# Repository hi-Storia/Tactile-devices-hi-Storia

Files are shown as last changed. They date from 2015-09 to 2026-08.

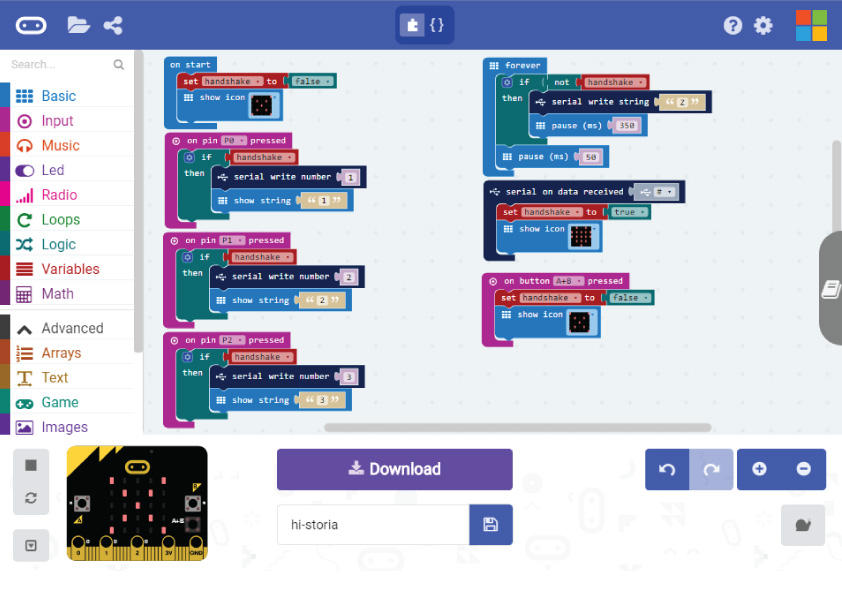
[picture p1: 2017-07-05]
Firmware/Microbit/microbit-blocks-for-hi-storia-player.jpg

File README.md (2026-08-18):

# Hi-Storia Tactile Devices

<p align="center">
  <a href="https://www.hi-storia.it/audioguida-tattile/">
    Hi-Storia tactile device
  </a>
</p>

Open-source firmware and hardware references for **Hi-Storia tactile audio guides**: 3D-printed cultural heritage models with capacitive touch activators that trigger audio and multimedia content.

Learn more about the project:

- [What is a Hi-Storia tactile audio guide?](https://www.hi-storia.it/audioguida-tattile/)
- [Hardware and electronics](https://www.hi-storia.it/audioguida-tattile/hardware/)

## Current reference architecture

The **2026 reference implementation** for new Hi-Storia tactile devices is:

**Arduino UNO R4 Minima + R4_Touch + USB serial + Hi-Storia Go on Android**

```text
3D-printed tactile model
        ↓
capacitive activators
        ↓
Arduino UNO R4 Minima
        ↓
USB serial · T1 / T2 / T3 / ...
        ↓
Android smartphone
        ↓
Hi-Storia Go
        ↓
audio and interactive content
```

This architecture keeps the electronics simple, visible and repairable, while allowing an Android smartphone — including a reused or refurbished device — to act as the player and configuration interface.

## Supported hardware

| Board | Touch sensing | Connection | Status | Field-tested on |
| --- | --- | --- | --- | --- |
| **Arduino UNO R4 Minima** | `R4_Touch` / built-in CTSU | USB serial | **Reference hardware** | Torpignattara, Rome (2026) |
| **ESP32** | Native capacitive touch | USB serial + Bluetooth Classic | **Supported alternative** | San Flaviano (2026) |
| Arduino UNO R3 | Legacy capacitive sensing | USB serial | Legacy | Previous Hi-Storia devices |
| Arduino Micro | Legacy capacitive sensing | USB serial | Legacy | Previous Hi-Storia devices |
| BBC micro:bit | Previous implementation | Serial / project-specific | Legacy / educational | Previous Hi-Storia workshops |

The older implementations remain in the repository for compatibility, documentation and educational reuse.

## Arduino UNO R4 Minima

The UNO R4 Minima is the current reference board for new Hi-Storia devices.

The reference firmware uses the [`R4_Touch`](https://github.com/delta-G/R4_Touch) library to access the capacitive touch sensing unit built into the UNO R4 microcontroller.

Current reference sketch:

```text
Firmware/Arduino/historia_arduino_uno_r4/
└── historia_arduino_uno_r4.ino
```

The current Hi-Storia configuration uses touch-capable pins:

```text
2, 3, 8, 9, 11
```

### R4_Touch hardware note

On the **UNO R4 Minima**, `R4_Touch` requires a capacitor between **TSCAP (pin 10)** and **GND**. The library recommends approximately **10 nF**.

The firmware uses single-scan touch acquisition, the configuration field-tested on the Torpignattara tactile device.

## ESP32

ESP32 is maintained as a supported alternative for installations where its integrated features are useful.

The Hi-Storia ESP32 firmware uses:

- native ESP32 capacitive touch inputs;
- USB serial;
- Bluetooth Classic;
- persistent threshold configuration through `Preferences`.

Reference sketch:

```text
Firmware/ESP32/historia_esp32/
└── historia_esp32.ino
```

This implementation was field-tested on the **San Flaviano Hi-Storia tactile device (2026)**.

The reference Hi-Storia Go workflow currently uses USB serial. Bluetooth support in the ESP32 firmware can also be used by compatible players or custom integrations.

## Serial protocol

Current firmware implementations share a small text-based protocol.

### Board → player

```text
T1
T2
T3
...
MSG:HI-STORIA READY
```

`T<n>` means that tactile activator number `n` has been touched.

### Player → board

```text
Z
SET:6500
PING
```

| Command | Meaning |
| --- | --- |
| `Z` | Reset the currently active tactile track |
| `SET:<value>` | Change and persist the touch threshold |
| `PING` | Test the connection; the board replies with `PONG` |

This keeps the firmware independent from the content itself: the board reports tactile events, while the player decides which audio or multimedia content is associated with each activator.

## Default player: Hi-Storia Go

The reference player for current Hi-Storia tactile devices is **[Hi-Storia Go](https://github.com/hi-Storia/Hi-Storia-Go)**, an open-source Android application.

Hi-Storia Go turns an Android smartphone into the player for a tactile model. It receives events such as `T1`, `T2` and `T3` from the board and associates them with the corresponding audio tracks.

The app is designed to make projects configurable directly from the phone and to support the reuse of older Android smartphones as dedicated players.

Hi-Storia Go is currently under active development and its public repository should be considered an **alpha release**.

## Repository layout

```text
Firmware/
├── Arduino/
│   ├── historia_arduino_uno_r4/
│   │   └── historia_arduino_uno_r4.ino
│   ├── historia_arduino_uno_r3/
│   │   └── historia_arduino_uno_r3.ino
│   └── historia_arduino_micro/
│       └── historia_arduino_micro.ino
│
├── ESP32/
│   └── historia_esp32/
│       └── historia_esp32.ino
│
└── Microbit/
    └── ...
```

Some legacy material may still use older directory or sketch names. These files document previous generations of Hi-Storia hardware.

## About Hi-Storia

Hi-Storia is an educational and cultural heritage project in which students and teachers research local heritage and build interactive tactile devices through 3D modelling and printing, electronics, coding, writing and audio production.

The tactile models are designed for shared use and include interaction modes intended to improve access for blind and partially sighted visitors.

More information:

- [Hi-Storia](https://www.hi-storia.it/)
- [Tactile audio guides](https://www.hi-storia.it/audioguida-tattile/)
- [Hardware](https://www.hi-storia.it/audioguida-tattile/hardware/)
- [Hi-Storia Go](https://github.com/hi-Storia/Hi-Storia-Go)

## License

The firmware in this repository is released under the **GNU General Public License v2.0 (GPL-2.0)**. See [LICENSE](LICENSE).

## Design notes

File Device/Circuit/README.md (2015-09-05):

# Importante
Nell'esempio, i file 3D per il dispositivo rappresentante la Basilica di San Bernardino a L'Aquila
In attesa del file Eagle, importiamo il file Dwg

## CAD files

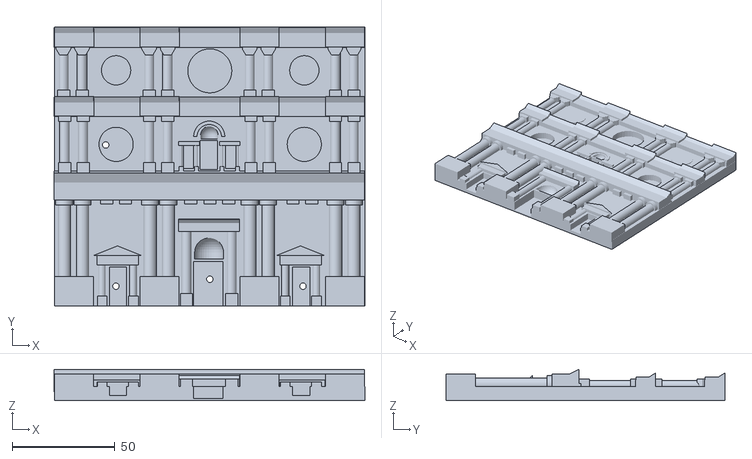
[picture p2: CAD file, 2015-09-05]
Device/3D print/Edificio.stl
151.3 x 135.7 x 15.2

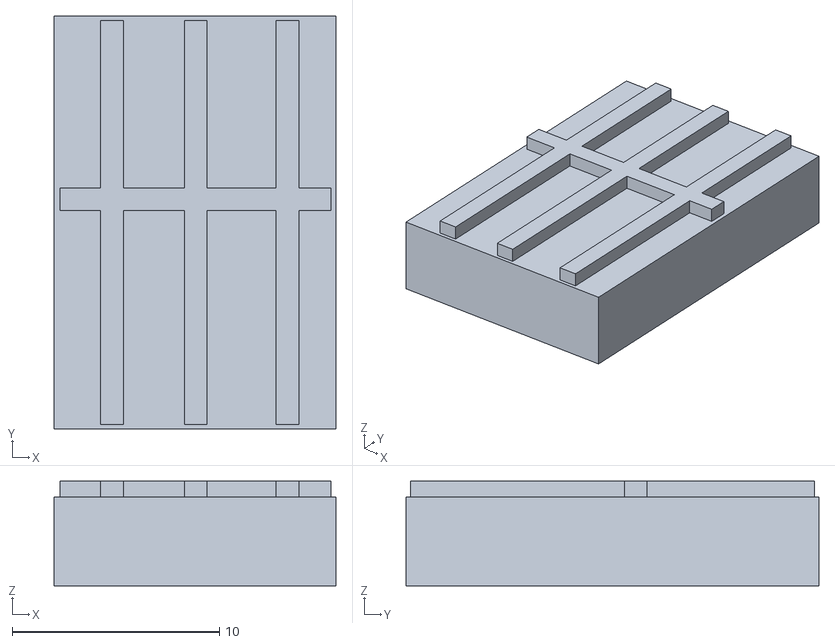
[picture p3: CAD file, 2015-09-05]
Device/3D print/Elementi conduttivi/5.2 portone principale conduttivo (repaired).stl
13.6 x 19.9 x 5.05

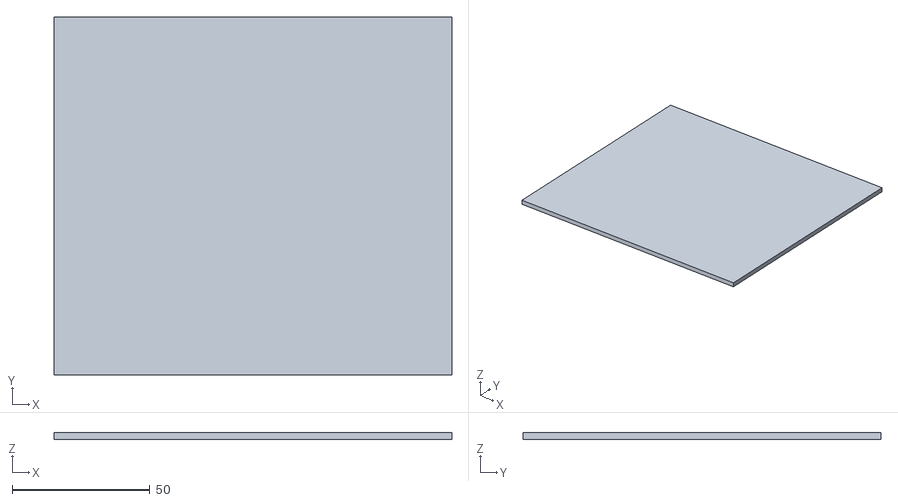
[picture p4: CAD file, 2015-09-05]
Device/3D print/Coperchio.stl
144.6 x 130.1 x 2.50

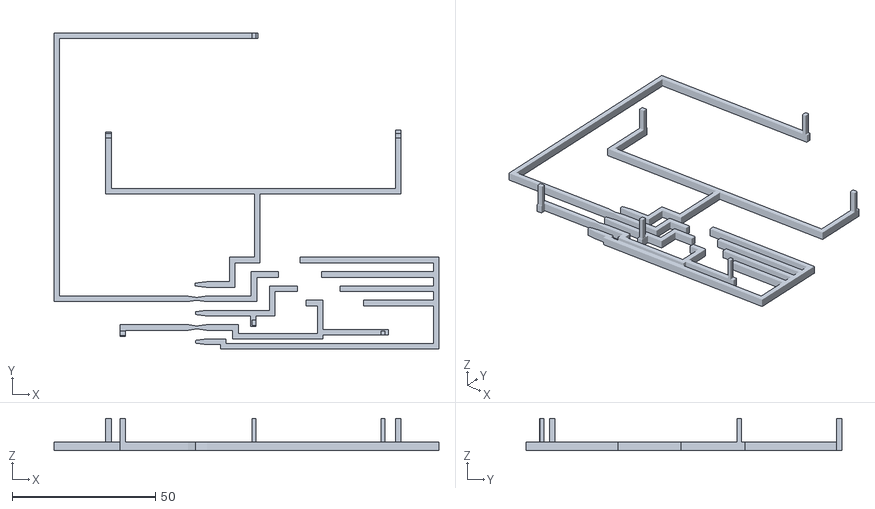
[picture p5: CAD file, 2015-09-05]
Device/3D print/Elementi conduttivi/Circuito capacitivo.stl
134.6 x 110.4 x 11.3

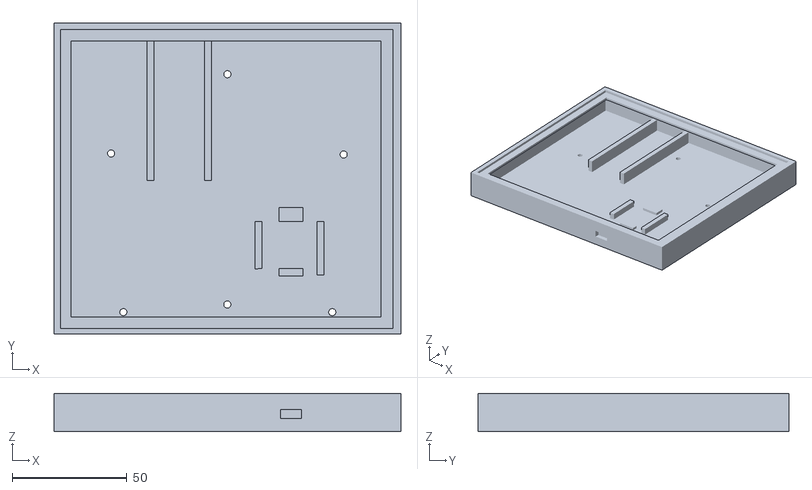
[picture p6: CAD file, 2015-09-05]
Device/3D print/Box circuito.stl
151.1 x 135.7 x 16.6

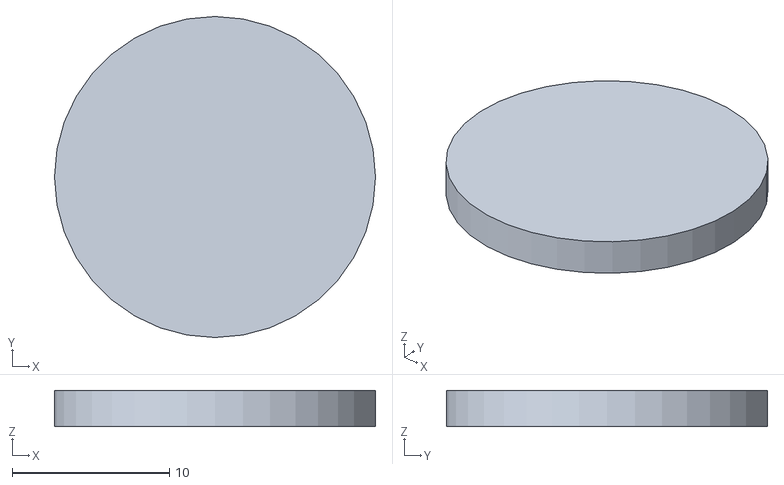
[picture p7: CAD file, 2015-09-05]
Device/3D print/Elementi conduttivi/5.3 rosone centrale conduttivo (repaired).stl
20.4 x 20.4 x 2.30

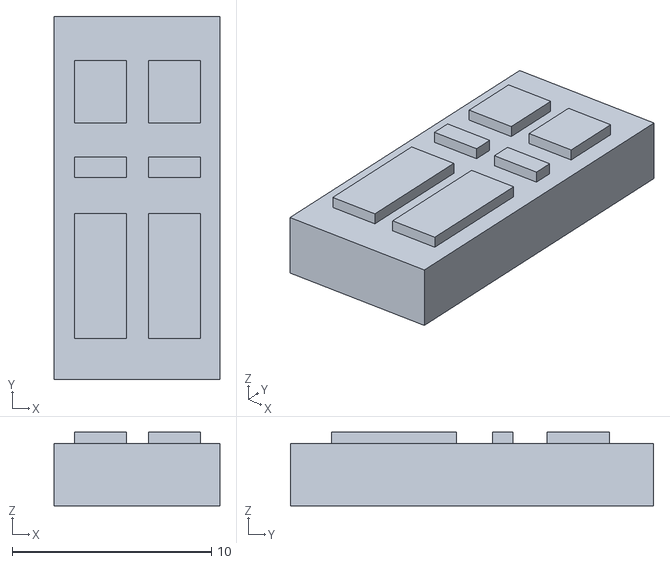
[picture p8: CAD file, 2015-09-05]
Device/3D print/Elementi conduttivi/5.1 portone laterale conduttivo (repaired).stl
8.33 x 18.2 x 3.69

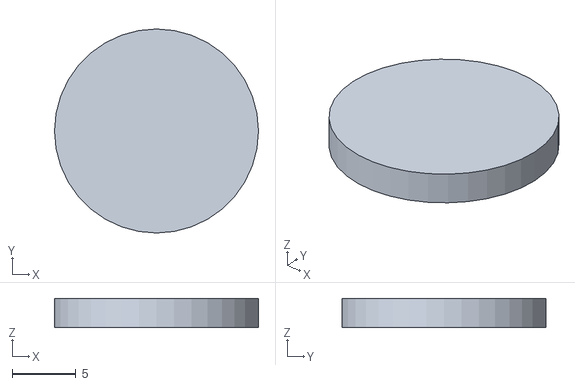
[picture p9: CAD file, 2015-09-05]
Device/3D print/Elementi conduttivi/5.4 rosoncino laterale conduttivo (repaired).stl
16.0 x 16.0 x 2.30

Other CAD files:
Device/Circuit/Circuito MICRO+ACCELE+BT+10 SENSORI.dwg

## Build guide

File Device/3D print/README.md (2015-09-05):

# Importante
Nell'esempio, i file 3D per il dispositivo rappresentante la Basilica di San Bernardino a L'Aquila
Sono presenti sia le parti conduttive che quelle in plastica normale.

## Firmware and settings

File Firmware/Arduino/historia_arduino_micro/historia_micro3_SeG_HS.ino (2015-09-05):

// mpu6050
#include "I2Cdev.h"
//#include "MPU6050.h"
#include "MPU6050_6Axis_MotionApps20.h"
#if I2CDEV_IMPLEMENTATION == I2CDEV_ARDUINO_WIRE
    #include "Wire.h"
#endif
// capacitive & BT
#include <CapacitiveSensor.h>

char blueToothVal;           //value sent over via bluetooth
char lastValue;              //stores last state of device (on/off)

char val;
int delayVal=500;
boolean handshake=false;
CapacitiveSensor capSensor3 = CapacitiveSensor(12,6);
CapacitiveSensor capSensor4 = CapacitiveSensor(12,8);
CapacitiveSensor capSensor5 = CapacitiveSensor(12,9);
CapacitiveSensor capSensor6 = CapacitiveSensor(12,10);
CapacitiveSensor capSensor7 = CapacitiveSensor(12,11);
CapacitiveSensor capSensor8 = CapacitiveSensor(12,18);
CapacitiveSensor capSensor9 = CapacitiveSensor(12,19);
CapacitiveSensor capSensor10 = CapacitiveSensor(12,20);
CapacitiveSensor capSensor11 = CapacitiveSensor(12,5);
CapacitiveSensor capSensor12 = CapacitiveSensor(12,4);
int threshold = 150; 
int tocco= -1;
int traccia=0;
int pausa=-1;
int fermadelay=0;

void setup() {
  Serial.begin(9600);
  Serial1.begin(9600);
  /*while (!Serial1) {
    ; // wait for serial port to connect. Needed for Leonardo only
  }*/
}
 
 
void loop() {
   if(!handshake){
    Serial.write('Z');
    Serial1.println('Z');
     if (Serial.available()) { // If data is available to read,
       val = Serial.read(); // read it and store it in val
       if (val == 'Z') { // If 1 was received
         delayVal=250;
         handshake=true;
       } else {
         if (Serial1.available()) { // If data is available to read,
             val = Serial1.read(); // read it and store it in val
             if (val == 'Z') { // If 1 was received
               delayVal=250;
               handshake=true;
             }
         }
       }
       delay(10); // Wait 10 milliseconds for next reading
     }
   }else{
  //CAPACITIVE
  int tocco= -1;
  int traccia=0;
  long sensorValue3 = capSensor3.capacitiveSensor(30);
  long sensorValue4 = capSensor4.capacitiveSensor(30);
  long sensorValue5 = capSensor5.capacitiveSensor(30);
  long sensorValue6 = capSensor6.capacitiveSensor(30);
  long sensorValue7 = capSensor7.capacitiveSensor(30);
  long sensorValue8 = capSensor8.capacitiveSensor(30);
  long sensorValue9 = capSensor9.capacitiveSensor(30);
  long sensorValue10 = capSensor10.capacitiveSensor(30);
  long sensorValue11 = capSensor11.capacitiveSensor(30);
  long sensorValue12 = capSensor12.capacitiveSensor(30);
  
  if(sensorValue11 > threshold) {
      traccia=1;
      tocco++;
  }
  if(sensorValue12 > threshold) {
      traccia=5; //capes
      tocco++;
  }
  if(sensorValue3 > threshold) {
      traccia=10;
      tocco++;
  }
  if(sensorValue4 > threshold) {
      traccia=7;
      tocco++;
  }
  if(sensorValue5 > threshold) {
      traccia=4;
      tocco++;
  }
  if(sensorValue6 > threshold) {
      traccia=8;
      tocco++;
  }
  if(sensorValue7 > threshold) {
      traccia=9; //PNGS
      tocco++;
  }
  if(sensorValue8 > threshold) {
      traccia=2;
      tocco++;
  }
  if(sensorValue9 > threshold) {
      traccia=3;
      tocco++;
  }
  if(sensorValue10 > threshold) {
      traccia=6; //tirino
      tocco++;
  }
  
  if(tocco>-1) {
    
      if(tocco==0){
        Serial1.println(traccia);
      }else{
        Serial1.println(90); 
      }
      
      if(tocco==0){
        //Serial.println(traccia);
        Serial.write(traccia);
      }else{
        //Serial.println(90); 
        Serial.write(90);     
      } 
  fermadelay++;
  }else{
  fermadelay--;
  }
  }
  delay(delayVal);
}

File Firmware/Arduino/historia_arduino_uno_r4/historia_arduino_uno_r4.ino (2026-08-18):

/*
 * Hi-Storia tactile device firmware
 * Board: Arduino UNO R4
 * Touch sensing: R4_Touch (single-scan mode)
 * Connection: USB serial
 * Persistent configuration: EEPROM
 *
 * Tested on:
 * - Torpignattara Hi-Storia tactile device (Rome, 2026)
 *
 * Protocol:
 * - T<n>       touch event for sensor n (for example: T1)
 * - Z          reset active track
 * - SET:<n>    set and save touch threshold
 * - PING       connection test; replies with PONG
 *
 * Dependencies:
 * - R4_Touch
 * - EEPROM
 *
 * The touch sensors are read in single-scan mode rather than free-running
 * mode. This is the configuration validated on the Torpignattara device.
 */

#include <R4_Touch.h>
#include <EEPROM.h>
#include <string.h>
#include <stdlib.h>

const uint8_t pinSensori[] = {2, 3, 8, 9, 11};
const int numSensori = sizeof(pinSensori) / sizeof(pinSensori[0]);

uint16_t soglia = 6500;
unsigned long ultimoTocco = 0;
int tracciaAttiva = 0;

const int debounceMs = 100;
const uint16_t minRaw = 1;
const uint16_t maxReasonable = 65000;
constexpr int EEPROM_ADDR = 0;

TouchSensor sensors[numSensori];

// Sends one protocol message terminated with CRLF.
void sendLine(const String &s) {
  Serial.print(s);
  Serial.print("\r\n");
}

void gestisciComando(char *comando) {
  while (*comando == ' ' || *comando == '\t' || *comando == '\r' || *comando == '\n') comando++;
  if (comando[0] == '\0') return;

  // Reset the active track after playback has ended.
  if ((comando[0] == 'Z' || comando[0] == 'z') && comando[1] == '\0') {
    tracciaAttiva = 0;
    sendLine("MSG:RESET OK");
    return;
  }

  // Update and persist the touch threshold.
  if (strncmp(comando, "SET:", 4) == 0 || strncmp(comando, "set:", 4) == 0) {
    int nuovaSoglia = atoi(comando + 4);
    if (nuovaSoglia > 1000 && nuovaSoglia < 20000) {
      soglia = (uint16_t)nuovaSoglia;
      for (int i = 0; i < numSensori; i++) sensors[i].setThreshold(soglia);
      EEPROM.put(EEPROM_ADDR, soglia);
      sendLine(String("MSG:Soglia salvata a ") + soglia);
    } else {
      sendLine("MSG:ERRORE soglia");
    }
    return;
  }

  // Connection test.
  if (strcmp(comando, "PING") == 0 || strcmp(comando, "ping") == 0) {
    sendLine("PONG");
  }
}

void leggiComandiSeriali() {
  static char commandBuffer[48];
  static uint8_t commandIndex = 0;

  while (Serial.available()) {
    char c = (char)Serial.read();
    if (c == '\r') continue;

    if (c == '\n') {
      commandBuffer[commandIndex] = '\0';
      gestisciComando(commandBuffer);
      commandIndex = 0;
      continue;
    }

    if (commandIndex < sizeof(commandBuffer) - 1) {
      commandBuffer[commandIndex++] = c;
    } else {
      commandIndex = 0;
      sendLine("MSG:ERRORE comando troppo lungo");
    }
  }
}

void setup() {
  Serial.begin(115200);
  while (!Serial) { }

  EEPROM.get(EEPROM_ADDR, soglia);
  if (soglia < 1000 || soglia > 20000) soglia = 6500;

  Serial.println("Sistema Avviato (UNO R4 + R4_Touch single-scan).");
  Serial.print("Soglia attuale: ");
  Serial.println(soglia);

  for (int i = 0; i < numSensori; i++) {
    bool ok = sensors[i].begin(pinSensori[i], soglia);
    if (!ok) {
      Serial.print("ERRORE: pin non supportato o gia in uso: ");
      Serial.println(pinSensori[i]);
    }
  }

  sendLine("MSG:HI-STORIA READY");
}

void loop() {
  leggiComandiSeriali();

  if (millis() - ultimoTocco > (unsigned long)debounceMs) {
    TouchSensor::startSingle();

    int hitSensor = 0;
    uint16_t hitVal = 0;

    // Read all sensors and keep the first sensor above the threshold.
    for (int i = 0; i < numSensori; i++) {
      uint16_t raw = sensors[i].readRaw();
      if (raw < minRaw || raw > maxReasonable) {
        raw = (raw < minRaw) ? minRaw : maxReasonable;
      }

      // Continuous diagnostic output, compatible with Serial Plotter.
      Serial.print("S");
      Serial.print(i + 1);
      Serial.print(":");
      Serial.print(raw);
      if (i == (numSensori - 1)) Serial.println();
      else Serial.print("\t");

      if (hitSensor == 0 && raw > soglia) {
        hitSensor = i + 1;
        hitVal = raw;
      }
    }

    if (hitSensor != 0) {
      if (hitSensor != tracciaAttiva) {
        sendLine(String("T") + hitSensor);
        tracciaAttiva = hitSensor;
      }
      ultimoTocco = millis();
    }
  }

  delay(40);
}

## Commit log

2015-09-05 Firmware & Devices schemes
    Created firmware for Arduino Uno and Micro, with BT breackout and two
    3-axis accelerometer.
    Create samples of stl and circuit
    [5.1 portone laterale conduttivo (repaired).stl, 5.2 portone principale conduttivo (repaired).stl, 5.3 rosone centrale conduttivo (repaired).stl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]
2015-09-05 Java app 0.6
    Create a Processing scretch. The application interfaces with the
    hi-Storia device, allowing the use of content in response to the user's
    touch
2015-09-05 Java app sample data
    Load example of audio-guide data
2016-06-15 Create historia_arduino_uno.ino
    Arduino code for "Simple setup devices": only capacitive sensors, without accelerometer, sonar sensor or bluetooth module
2016-06-15 Delete old sketch
    Delete old Arduino sketch
2024-07-10 Create sensoriTattili.ino
    Add new version of sketch for Tactile Device, only with capacitive sensors
2026-08-18 Add Arduino UNO R4 and ESP32 firmware support
    ## Summary
    Updates the Hi-Storia tactile devices repository with the current hardware implementations and documentation.
    ### Added
    - Arduino UNO R4 Minima firmware
    - uses `R4_Touch` and the UNO R4 capacitive touch unit
    - USB serial communication with the Hi-Storia player
    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
